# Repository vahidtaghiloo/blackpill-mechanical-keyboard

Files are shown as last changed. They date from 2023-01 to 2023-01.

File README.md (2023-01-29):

# blackpill-mechanical-keyboard
stm32f411ceu6 black pill 44 key mechanical keyboard, inspired by Keyboardio Atreus (keyboardio.io)

The project is complete, the PCBs are manufactured and tested. The binary firmware
is [here](https://github.com/vahidtaghiloo/qmk-firmware-build/releases/tag/test)
and the qmk modified firmware is [here](https://github.com/vahidtaghiloo/qmk_firmware/tree/master/keyboards/blackpill_mechanical_keyboard)

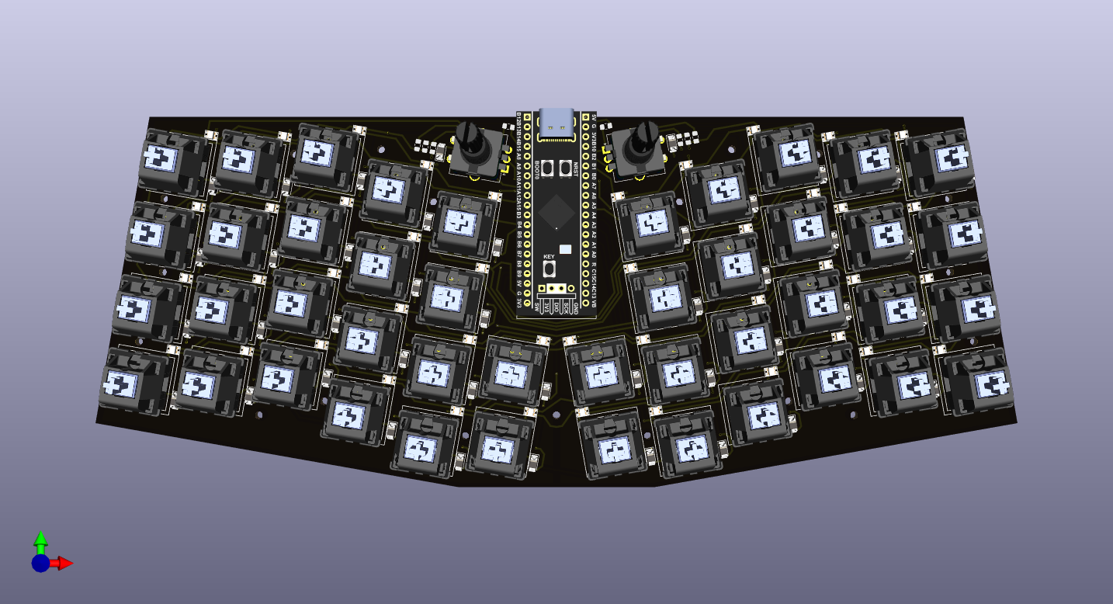
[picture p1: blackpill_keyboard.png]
kb

kb_pcb
kb_video

# A few words:
- Due to current limitation of the onboard voltage regulator, some backlight 
  animations are not smooth. Changing the regulator is not an option because I
  could not find a similar package.
- Due to the higher frequency crystal (25 MHz), sometimes the black pill does not
  enter the DFU mode. Using a 12 Mhz oscilator seems to solve the issue.

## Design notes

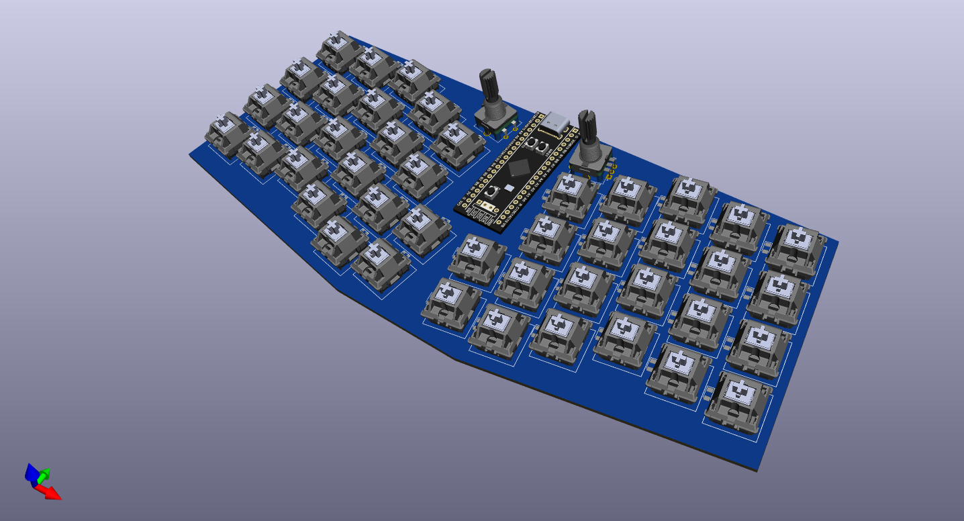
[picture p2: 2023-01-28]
kicad/images/keyboard1.png

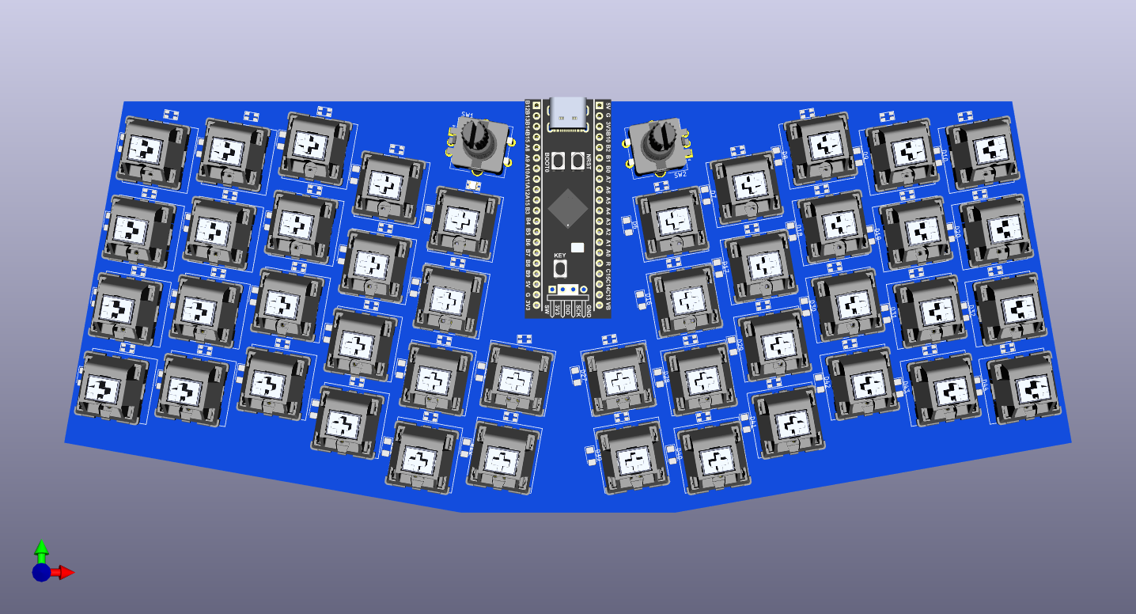
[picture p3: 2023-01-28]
kicad/images/keyboard3.png

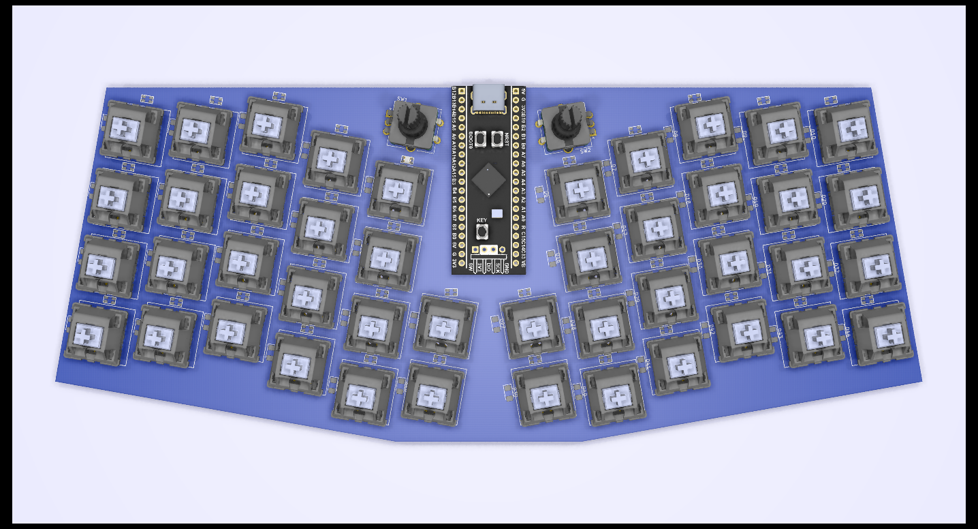
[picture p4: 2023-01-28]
kicad/images/keyboard4.png

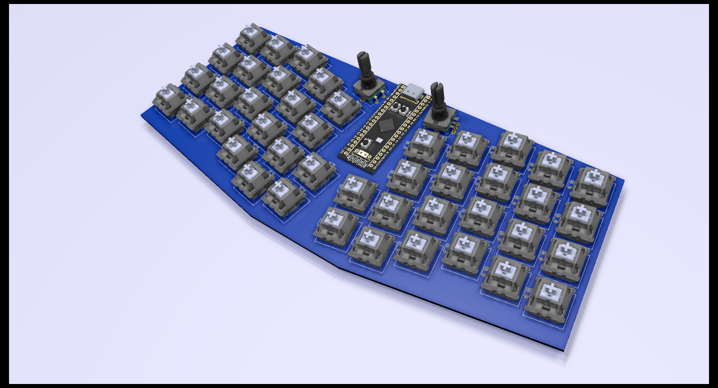
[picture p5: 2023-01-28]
kicad/images/keyboard2.png

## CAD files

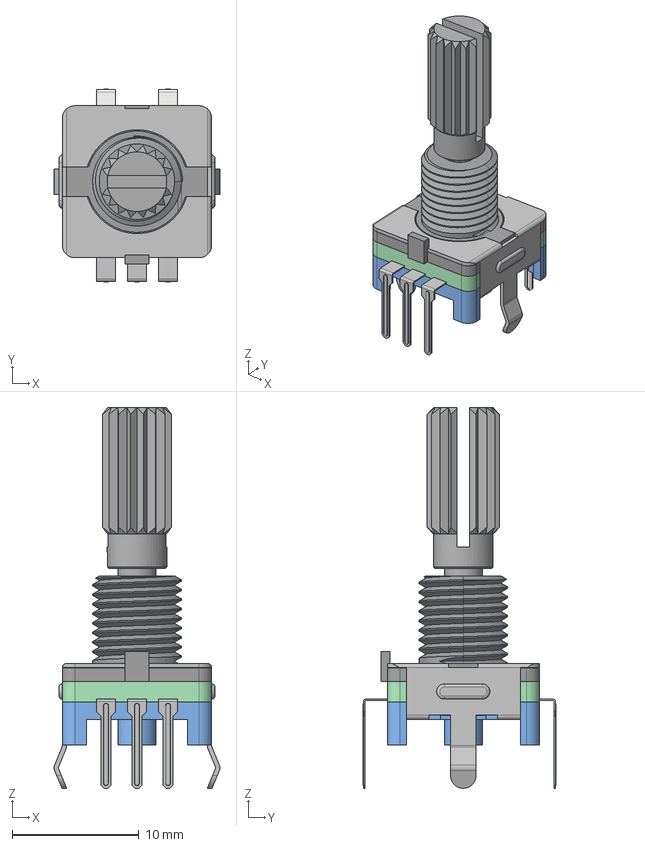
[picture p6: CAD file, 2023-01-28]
kicad/3d_models/EC11_Rotary_Encoder_Switched.step
13.1 x 15.3 x 30.1 mm

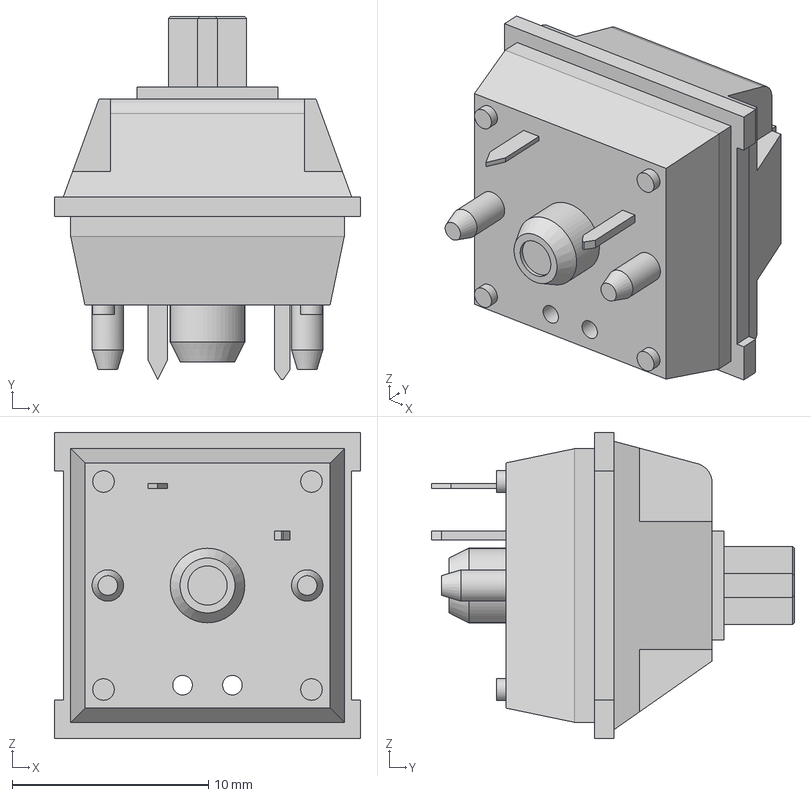
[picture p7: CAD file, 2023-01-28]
kicad/3d_models/mx_style_switch.stp
15.6 x 18.5 x 15.6 mm

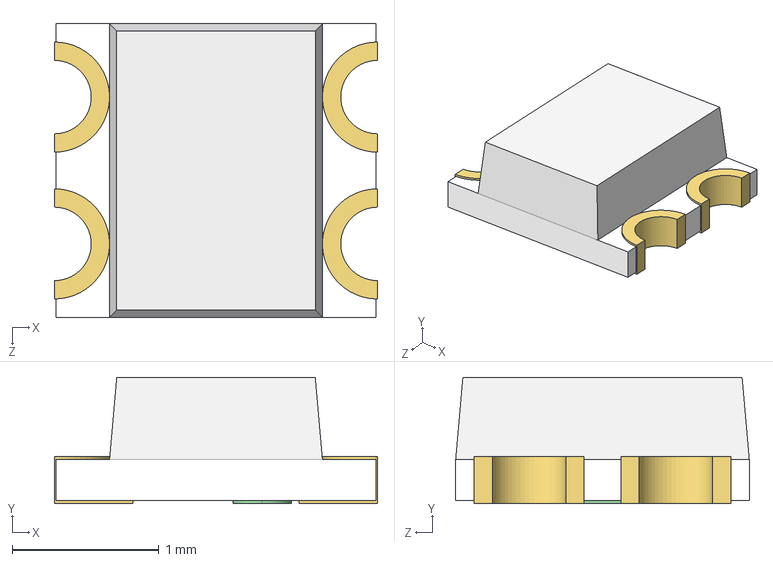
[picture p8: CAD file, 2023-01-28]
kicad/3d_models/WS2812_2020.STEP
2.20 x 0.86 x 2.00 mm

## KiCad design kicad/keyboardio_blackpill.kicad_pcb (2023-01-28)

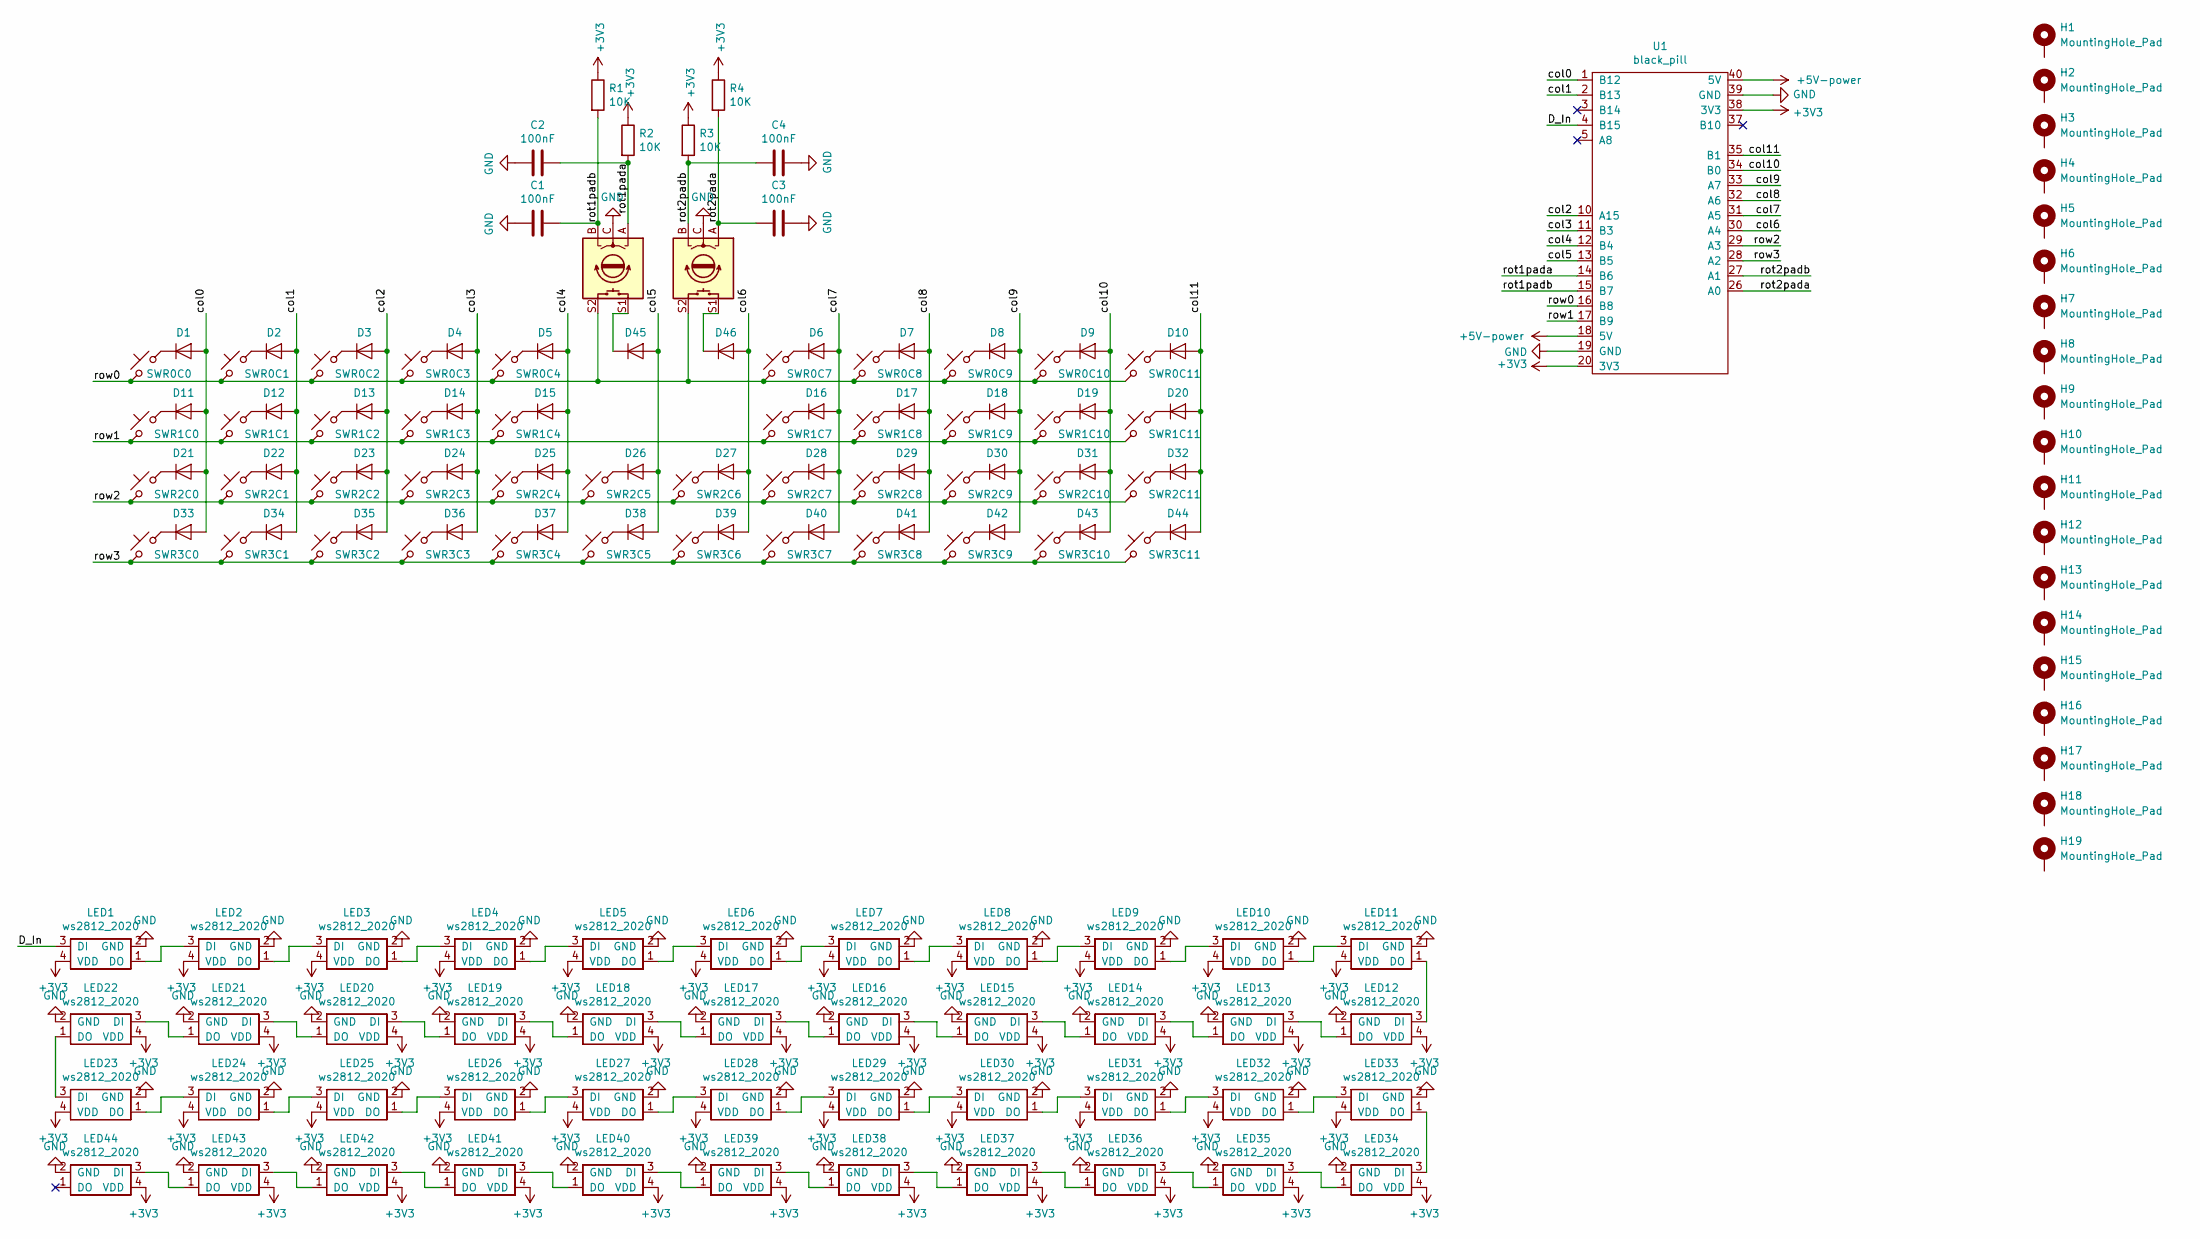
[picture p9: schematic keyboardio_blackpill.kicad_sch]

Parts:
C1, C2, C3, C4: 100nF; C_0805_2012Metric_Pad1.15x1.40mm_HandSolder
D1, D2, D3, D4, D5, D6, D7, D8, D9, D10, D11, D12, D13, D14, D15, D16, D17, D18, D19, D20, D21, D22, D23, D24, D25, D26, D27, D28, D29, D30, D31, D32, D33, D34, D35, D36, D37, D38, D39, D40, D41, D42, D43, D44, D45, D46: 1N4148; D_1206_3216Metric_Pad1.42x1.75mm_HandSolder
H1, H2, H3, H4, H5, H6, H7, H8, H9, H10, H11, H12, H13, H14, H15, H16, H17, H18, H19: MountingHole_Pad; MountingHole_2mm
LED1, LED2, LED3, LED4, LED5, LED6, LED7, LED8, LED9, LED10, LED11, LED12, LED13, LED14, LED15, LED16, LED17, LED18, LED19, LED20, LED21, LED22, LED23, LED24, LED25, LED26, LED27, LED28, LED29, LED30, LED31, LED32, LED33, LED34, LED35, LED36, LED37, LED38, LED39, LED40, LED41, LED42, LED43, LED44: ws2812_2020
R1, R2, R3, R4: 10K; R_0805_2012Metric_Pad1.15x1.40mm_HandSolder
SW1, SW2: Rotary_Encoder_Switch; RotaryEncoder_Alps_EC12E-Switch_Vertical_H20mm_CircularMoun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
SWR0C0, SWR0C1, SWR0C2, SWR0C3, SWR0C4, SWR0C7, SWR0C8, SWR0C9, SWR0C10, SWR0C11, SWR1C0, SWR1C1, SWR1C2, SWR1C3, SWR1C4, SWR1C7, SWR1C8, SWR1C9, SWR1C10, SWR1C11, SWR2C0, SWR2C1, SWR2C2, SWR2C3, SWR2C4, SWR2C5, SWR2C6, SWR2C7, SWR2C8, SWR2C9, SWR2C10, SWR2C11, SWR3C0, SWR3C1, SWR3C2, SWR3C3, SWR3C4, SWR3C5, SWR3C6, SWR3C7, SWR3C8, SWR3C9, SWR3C10, SWR3C11: SW_Push_45deg; cherryMX
U1: black_pill; stm32_blackpill

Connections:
+3V3: LED1.4 (VDD), LED2.4 (VDD), LED3.4 (VDD), LED4.4 (VDD), LED5.4 (VDD), LED6.4 (VDD), LED7.4 (VDD), LED8.4 (VDD), LED9.4 (VDD), LED10.4 (VDD), LED11.4 (VDD), LED12.4 (VDD), LED13.4 (VDD), LED14.4 (VDD), LED15.4 (VDD), LED16.4 (VDD), LED17.4 (VDD), LED18.4 (VDD), LED19.4 (VDD), LED20.4 (VDD), LED21.4 (VDD), LED22.4 (VDD), LED23.4 (VDD), LED24.4 (VDD), LED25.4 (VDD), LED26.4 (VDD), LED27.4 (VDD), LED28.4 (VDD), LED29.4 (VDD), LED30.4 (VDD), LED31.4 (VDD), LED32.4 (VDD), LED33.4 (VDD), LED34.4 (VDD), LED35.4 (VDD), LED36.4 (VDD), LED37.4 (VDD), LED38.4 (VDD), LED39.4 (VDD), LED40.4 (VDD), LED41.4 (VDD), LED42.4 (VDD), LED43.4 (VDD), LED44.4 (VDD), R1.1, R2.1, R3.1, R4.1, U1.20 (3V3), U1.38 (3V3)
+5V: U1.18 (5V), U1.40 (5V)
/D_In: LED1.3 (DI), U1.4 (B15)
/col0: D1.2 (A), D11.2 (A), D21.2 (A), D33.2 (A), U1.1 (B12)
/col1: D2.2 (A), D12.2 (A), D22.2 (A), D34.2 (A), U1.2 (B13)
/col2: D3.2 (A), D13.2 (A), D23.2 (A), D35.2 (A), U1.10 (A15)
/col3: D4.2 (A), D14.2 (A), D24.2 (A), D36.2 (A), U1.11 (B3)
/col4: D5.2 (A), D15.2 (A), D25.2 (A), D37.2 (A), U1.12 (B4)
/col5: D26.2 (A), D38.2 (A), D45.2 (A), U1.13 (B5)
/col6: D27.2 (A), D39.2 (A), D46.2 (A), U1.30 (A4)
/col7: D6.2 (A), D16.2 (A), D28.2 (A), D40.2 (A), U1.31 (A5)
/col8: D7.2 (A), D17.2 (A), D29.2 (A), D41.2 (A), U1.32 (A6)
/col9: D8.2 (A), D18.2 (A), D30.2 (A), D42.2 (A), U1.33 (A7)
/col10: D9.2 (A), D19.2 (A), D31.2 (A), D43.2 (A), U1.34 (B0)
/col11: D10.2 (A), D20.2 (A), D32.2 (A), D44.2 (A), U1.35 (B1)
/rot1pada: C2.1, R2.2, SW2.A, U1.14 (B6)
/rot1padb: C1.1, R1.2, SW2.B, U1.15 (B7)
/rot2pada: C3.2, R4.2, SW1.A, U1.26 (A0)
/rot2padb: C4.2, R3.2, SW1.B, U1.27 (A1)
/row0: SW1.S2, SW2.S2, SWR0C0.1, SWR0C1.1, SWR0C2.1, SWR0C3.1, SWR0C4.1, SWR0C7.1, SWR0C8.1, SWR0C9.1, SWR0C10.1, SWR0C11.1, U1.16 (B8)
/row1: SWR1C0.1, SWR1C1.1, SWR1C2.1, SWR1C3.1, SWR1C4.1, SWR1C7.1, SWR1C8.1, SWR1C9.1, SWR1C10.1, SWR1C11.1, U1.17 (B9)
/row2: SWR2C0.1, SWR2C1.1, SWR2C2.1, SWR2C3.1, SWR2C4.1, SWR2C5.1, SWR2C6.1, SWR2C7.1, SWR2C8.1, SWR2C9.1, SWR2C10.1, SWR2C11.1, U1.29 (A3)
/row3: SWR3C0.1, SWR3C1.1, SWR3C2.1, SWR3C3.1, SWR3C4.1, SWR3C5.1, SWR3C6.1, SWR3C7.1, SWR3C8.1, SWR3C9.1, SWR3C10.1, SWR3C11.1, U1.28 (A2)
GND: C1.2, C2.2, C3.1, C4.1, LED1.2 (GND), LED2.2 (GND), LED3.2 (GND), LED4.2 (GND), LED5.2 (GND), LED6.2 (GND), LED7.2 (GND), LED8.2 (GND), LED9.2 (GND), LED10.2 (GND), LED11.2 (GND), LED12.2 (GND), LED13.2 (GND), LED14.2 (GND), LED15.2 (GND), LED16.2 (GND), LED17.2 (GND), LED18.2 (GND), LED19.2 (GND), LED20.2 (GND), LED21.2 (GND), LED22.2 (GND), LED23.2 (GND), LED24.2 (GND), LED25.2 (GND), LED26.2 (GND), LED27.2 (GND), LED28.2 (GND), LED29.2 (GND), LED30.2 (GND), LED31.2 (GND), LED32.2 (GND), LED33.2 (GND), LED34.2 (GND), LED35.2 (GND), LED36.2 (GND), LED37.2 (GND), LED38.2 (GND), LED39.2 (GND), LED40.2 (GND), LED41.2 (GND), LED42.2 (GND), LED43.2 (GND), LED44.2 (GND), SW1.C, SW2.C, U1.19 (GND), U1.39 (GND)
unnamed: D1.1 (K), SWR0C0.2
unnamed: D2.1 (K), SWR0C1.2
unnamed: D3.1 (K), SWR0C2.2
unnamed: D4.1 (K), SWR0C3.2
unnamed: D5.1 (K), SWR0C4.2
unnamed: D6.1 (K), SWR0C7.2
unnamed: D7.1 (K), SWR0C8.2
unnamed: D8.1 (K), SWR0C9.2
unnamed: D9.1 (K), SWR0C10.2
unnamed: D10.1 (K), SWR0C11.2
unnamed: D11.1 (K), SWR1C0.2
unnamed: D12.1 (K), SWR1C1.2
unnamed: D13.1 (K), SWR1C2.2
unnamed: D14.1 (K), SWR1C3.2
unnamed: D15.1 (K), SWR1C4.2
unnamed: D16.1 (K), SWR1C7.2
unnamed: D17.1 (K), SWR1C8.2
unnamed: D18.1 (K), SWR1C9.2
unnamed: D19.1 (K), SWR1C10.2
unnamed: D20.1 (K), SWR1C11.2
unnamed: D21.1 (K), SWR2C0.2
unnamed: D22.1 (K), SWR2C1.2
unnamed: D23.1 (K), SWR2C2.2
unnamed: D24.1 (K), SWR2C3.2
unnamed: D25.1 (K), SWR2C4.2
unnamed: D26.1 (K), SWR2C5.2
unnamed: D27.1 (K), SWR2C6.2
unnamed: D28.1 (K), SWR2C7.2
unnamed: D29.1 (K), SWR2C8.2
unnamed: D30.1 (K), SWR2C9.2
unnamed: D31.1 (K), SWR2C10.2
unnamed: D32.1 (K), SWR2C11.2
unnamed: D33.1 (K), SWR3C0.2
unnamed: D34.1 (K), SWR3C1.2
unnamed: D35.1 (K), SWR3C2.2
unnamed: D36.1 (K), SWR3C3.2
unnamed: D37.1 (K), SWR3C4.2
unnamed: D38.1 (K), SWR3C5.2
unnamed: D39.1 (K), SWR3C6.2
unnamed: D40.1 (K), SWR3C7.2
unnamed: D41.1 (K), SWR3C8.2
unnamed: D42.1 (K), SWR3C9.2
unnamed: D43.1 (K), SWR3C10.2
unnamed: D44.1 (K), SWR3C11.2
unnamed: D45.1 (K), SW2.S1
unnamed: D46.1 (K), SW1.S1
unnamed: LED1.1 (DO), LED2.3 (DI)
unnamed: LED2.1 (DO), LED3.3 (DI)
unnamed: LED3.1 (DO), LED4.3 (DI)
unnamed: LED4.1 (DO), LED5.3 (DI)
unnamed: LED5.1 (DO), LED6.3 (DI)
unnamed: LED6.1 (DO), LED7.3 (DI)
unnamed: LED7.1 (DO), LED8.3 (DI)
unnamed: LED8.1 (DO), LED9.3 (DI)
unnamed: LED10.1 (DO), LED11.3 (DI)
unnamed: LED9.1 (DO), LED10.3 (DI)
unnamed: LED11.1 (DO), LED12.3 (DI)
unnamed: LED12.1 (DO), LED13.3 (DI)
unnamed: LED13.1 (DO), LED14.3 (DI)
unnamed: LED14.1 (DO), LED15.3 (DI)
unnamed: LED15.1 (DO), LED16.3 (DI)
unnamed: LED16.1 (DO), LED17.3 (DI)
unnamed: LED17.1 (DO), LED18.3 (DI)
unnamed: LED18.1 (DO), LED19.3 (DI)
unnamed: LED19.1 (DO), LED20.3 (DI)
unnamed: LED20.1 (DO), LED21.3 (DI)
unnamed: LED21.1 (DO), LED22.3 (DI)
unnamed: LED22.1 (DO), LED23.3 (DI)
unnamed: LED23.1 (DO), LED24.3 (DI)
unnamed: LED24.1 (DO), LED25.3 (DI)
unnamed: LED25.1 (DO), LED26.3 (DI)
unnamed: LED26.1 (DO), LED27.3 (DI)
unnamed: LED27.1 (DO), LED28.3 (DI)
unnamed: LED28.1 (DO), LED29.3 (DI)
unnamed: LED29.1 (DO), LED30.3 (DI)
unnamed: LED30.1 (DO), LED31.3 (DI)
unnamed: LED31.1 (DO), LED32.3 (DI)
unnamed: LED32.1 (DO), LED33.3 (DI)
unnamed: LED33.1 (DO), LED34.3 (DI)
unnamed: LED34.1 (DO), LED35.3 (DI)
unnamed: LED35.1 (DO), LED36.3 (DI)
unnamed: LED36.1 (DO), LED37.3 (DI)
unnamed: LED37.1 (DO), LED38.3 (DI)
unnamed: LED38.1 (DO), LED39.3 (DI)
unnamed: LED39.1 (DO), LED40.3 (DI)
unnamed: LED40.1 (DO), LED41.3 (DI)
unnamed: LED41.1 (DO), LED42.3 (DI)
unnamed: LED42.1 (DO), LED43.3 (DI)
unnamed: LED43.1 (DO), LED44.3 (DI)

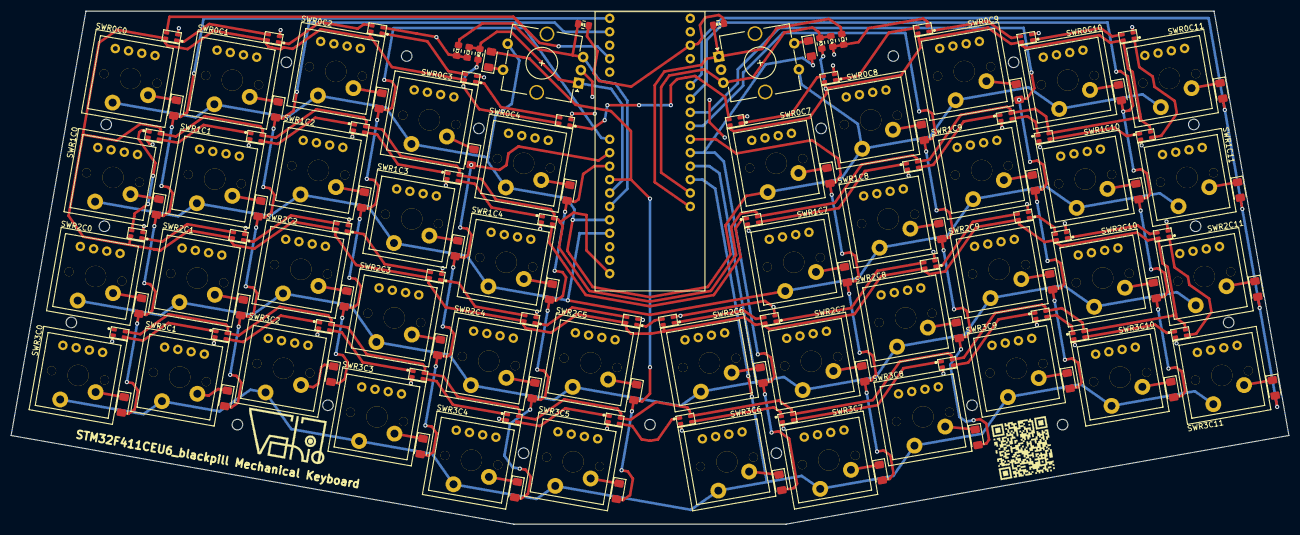
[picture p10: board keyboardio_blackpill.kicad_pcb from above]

Board: 2 copper layers, 241.6 x 97.0 mm, 164 parts (0 on the bottom side), 113 nets.

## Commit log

2023-01-28 feat: Add Blackpill_keyboard Kicad Files
    [EC11_Rotary_Encoder_Switched.step, WS2812_2020.STEP, keyboardio_blackpill.kicad_pcb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]
2023-01-29 chore: Add Keyboard PCB and Video
